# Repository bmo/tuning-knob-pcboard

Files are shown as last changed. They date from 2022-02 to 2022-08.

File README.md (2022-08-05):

# tuning-knob-pcboard  
https://github.com/bmo/tuning-knob-pcboard

This is a KiCAD PC Board design for a tuning knob that works with PowerSDR and SmartSDR and Remote Ham Radio (RHR). Uses STM32 hardware. Find the software that works with this here: https://github.com/bmo/hwcontrol

## Features:
- 24ppr encoder
- multiple ways to build it
- uses mostly-available STM32F103 "Blue Pill" PC boards, may also work with newer, more powerful, more available, and cheaper (!?) "Black Pill" PCBs using STM32F4xx CPUs (with code changes)
- through-hole parts
- 20-30 minute assembly
- traces already supplied for future expansion for footswitch inputs, flash memory, SPI-based displays
- works with RHR, PowerSDR, SmartSDR when used in conjunction with https://github.com/bmo/hwcontrol

## Version 1:
Build it two ways:
- snap-action tactile switches and 3mm LEDs
- small tactile switches with built-in LEDs
- isolated pin 40 to not prohibit "Black Pill" from being plugged in
hwcontrol_513k

## Version 2 (in Progress):
- Cherry MX or compatible "buttons"
- RGB LEDs for illumination

## Future:
- With a composite USB Device providing two CDC (serial) devices, a solution that provides a Knob and a de-bounced footswitch

## References:
- KiCAD library / design for Cherry Switch + RGB : https://github.com/sszczep/Cherry-MX-Breakout-Board

## Contributions
Thanks to @cjtheham for BOM and documentation!

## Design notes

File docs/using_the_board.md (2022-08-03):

All connections to a computer will be made by connecting a micro-USB cable to the STM-32 board, the other end into your computer/device.

# RemoteHamRadio

In order to use the board with RemoteHamRadio, you'll need to set it up like it is a FlexControl. 

Go to the devices tab on the bottom left-hand side. Go to the tab labeled FlexControl, click discover COM port, and then quickly unplug and re-plug in the USB cable for the device. RHR should detect the correct port and you'll be good to go to start using the VFO knob and tuning the bands.

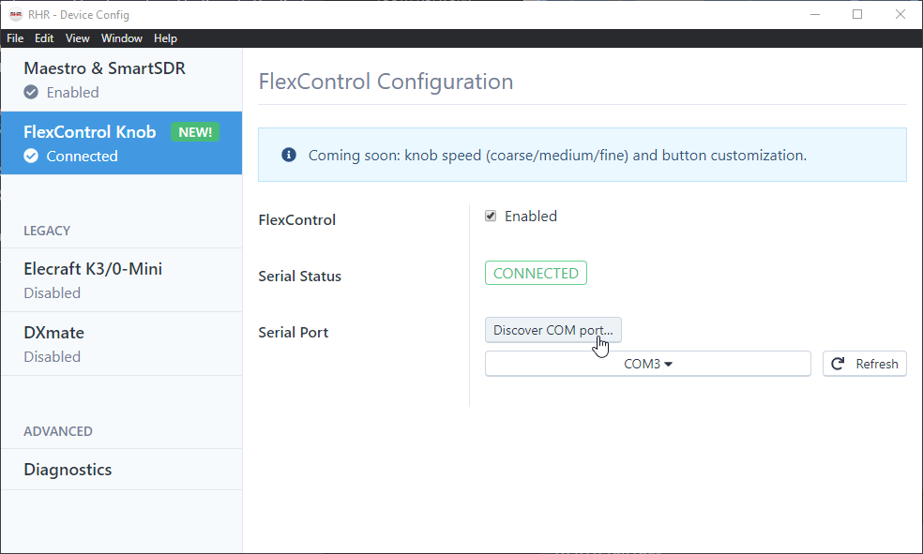
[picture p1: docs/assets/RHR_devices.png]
RemoteHamRadio devices panel for FlexControl


# SmartSDR

SmartSDR from Flex Radio should automatically detect the device, but sometimes it doesn't grab it right away. I've found that simply unplugging it, plugging it back in, and waiting around 20 seconds gets it to be recognized. From here, you'll automatically be able to start using it as a VFO knob.

If you want to change the features of the buttons, or clicking down on the knob, simply go to the tab at the top of the screen labeled Settings, and then click FlexControl. If the board is successfully connected, you'll be able to change the settings here.

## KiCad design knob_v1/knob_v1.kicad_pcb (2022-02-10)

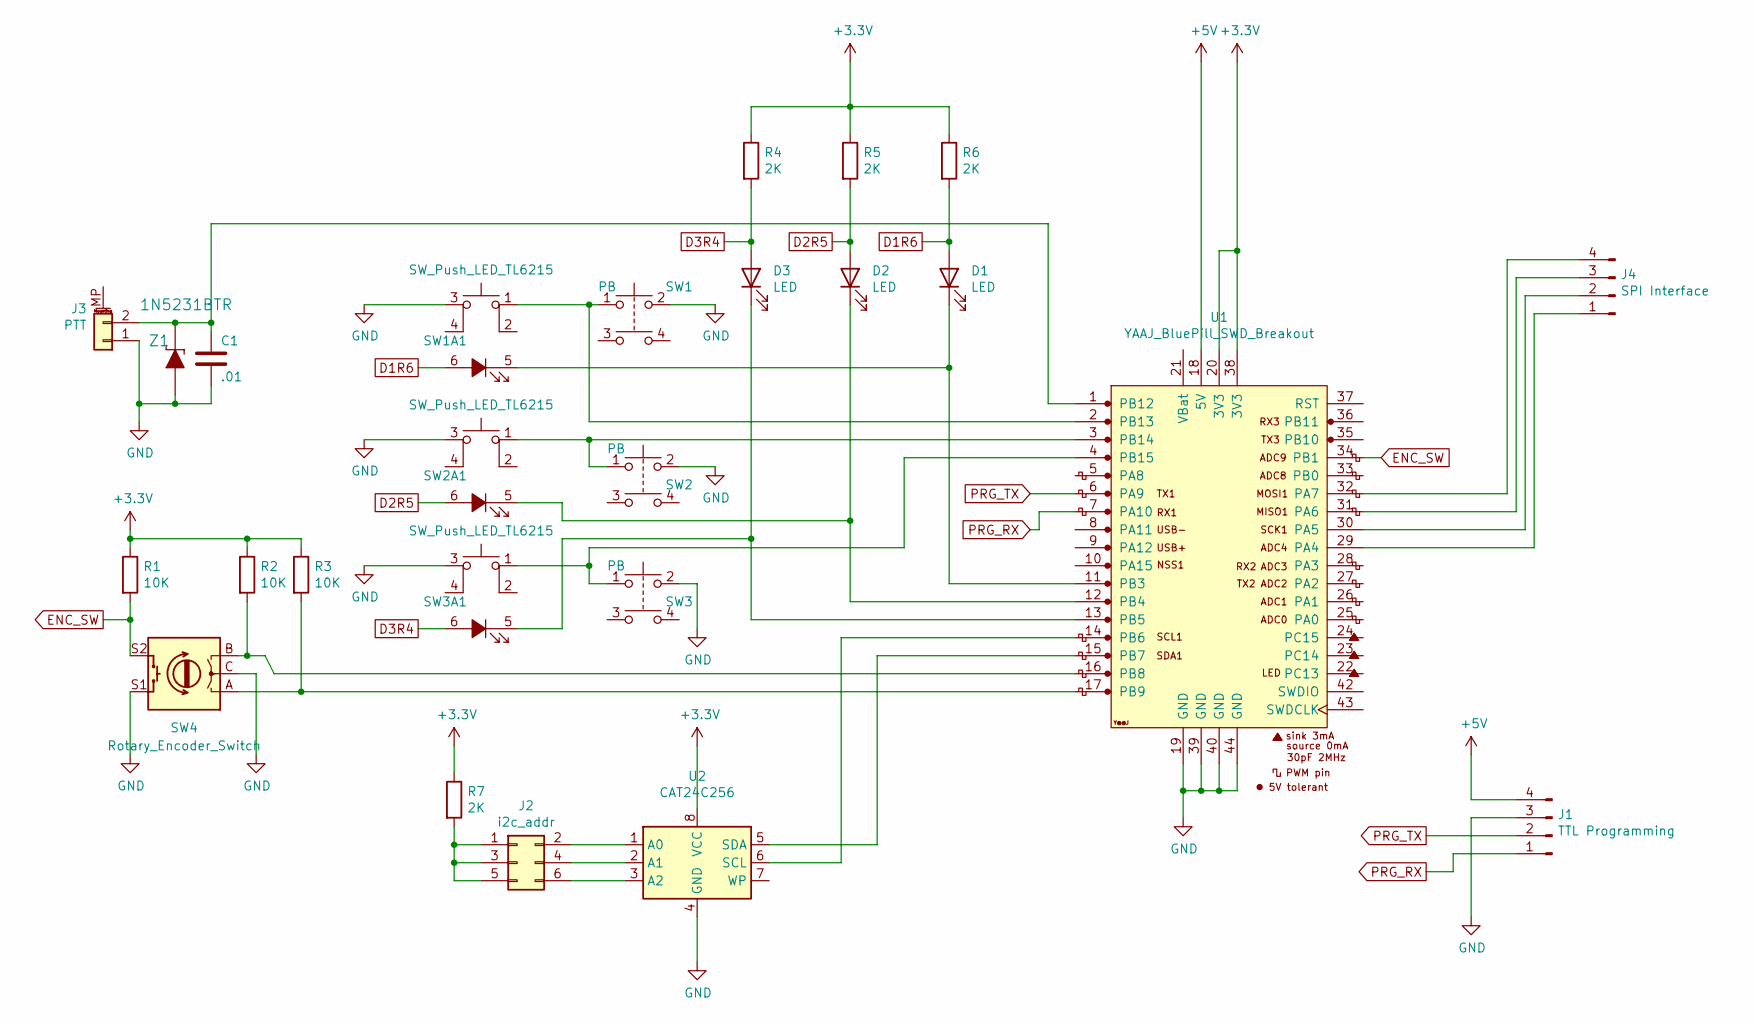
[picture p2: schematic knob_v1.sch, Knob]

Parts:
C1: .01; C_Disc_D3.0mm_W1.6mm_P2.50mm
D1, D2, D3: LED; LED_D3.0mm
J1: TTL Programming; PinHeader_1x04_P2.54mm_Vertical
J2: i2c_addr; PinHeader_2x04_P2.54mm_Vertical
J3: PTT; PinHeader_1x02_P2.54mm_Horizontal
J4: SPI Interface; PinHeader_1x04_P2.54mm_Vertical
R1, R2, R3: 10K; R_Axial_DIN0207_L6.3mm_D2.5mm_P7.62mm_Horizontal
R4, R5, R6, R7: 2K; R_Axial_DIN0207_L6.3mm_D2.5mm_P7.62mm_Horizontal
SW1, SW2, SW3: PB; SW_PUSH-12mm-corrected
SW1A1, SW2A1, SW3A1: SW_Push_LED_TL6215; TL6215V
SW4: Rotary_Encoder_Switch; RotaryEncoder_Alps_EC12E-Switch_Vertical_H20mm
U1: YAAJ_BluePill_SWD_Breakout; YAAJ_BluePill_SWD_1
U2: CAT24C256; SOIC8-1.27-5X4MM
Z1: 1N5231BTR; DO-35; MPN 1N5231BTR; Digi-Key_PN 1N5231BFSCT-ND

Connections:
+3V3: R1.1, R2.1, R3.1, R4.1, R5.1, R6.1, R7.1, U1.20 (3V3), U1.38 (3V3), U2.8 (VCC)
+5V: J1.4, U1.18 (5V)
D1R6: D1.2 (A), R6.2, SW1A1.6 (A)
D2R5: D2.2 (A), R5.2, SW2A1.6 (A)
D3R4: D3.2 (A), R4.2, SW3A1.6 (A)
ENC_SW: R1.2, SW4.S2, U1.34 (PB1)
GND: C1.2, J1.3, J3.1, SW1.2, SW1A1.3, SW2.2, SW2A1.3, SW3.2, SW3A1.3, SW4.C, SW4.S1, U1.19 (GND), U1.39 (GND), U1.40 (GND), U1.44 (GND), U2.4 (GND), Z1.A
unnamed: C1.1, J3.2, U1.1 (PB12), Z1.K
unnamed: D1.1 (K), SW1A1.5 (K), U1.11 (PB3)
unnamed: D2.1 (K), SW2A1.5 (K), U1.12 (PB4)
unnamed: D3.1 (K), SW3A1.5 (K), U1.13 (PB5)
unnamed: J2.1, J2.3, J2.5, R7.2
unnamed: J2.2, U2.1 (A0)
unnamed: J2.4, U2.2 (A1)
unnamed: J2.6, U2.3 (A2)
unnamed: J4.1, U1.29 (PA4)
unnamed: J4.2, U1.30 (PA5)
unnamed: J4.3, U1.31 (PA6)
unnamed: J4.4, U1.32 (PA7)
unnamed: R2.2, SW4.B, U1.16 (PB8)
unnamed: R3.2, SW4.A, U1.17 (PB9)
unnamed: SW1.1, SW1A1.1, U1.2 (PB13)
unnamed: SW2.1, SW2A1.1, U1.3 (PB14)
unnamed: SW3.1, SW3A1.1, U1.4 (PB15)
unnamed: U1.14 (PB6), U2.6 (SCL)
unnamed: U1.15 (PB7), U2.5 (SDA)
PRG_RX: J1.1, U1.7 (PA10)
PRG_TX: J1.2, U1.6 (PA9)

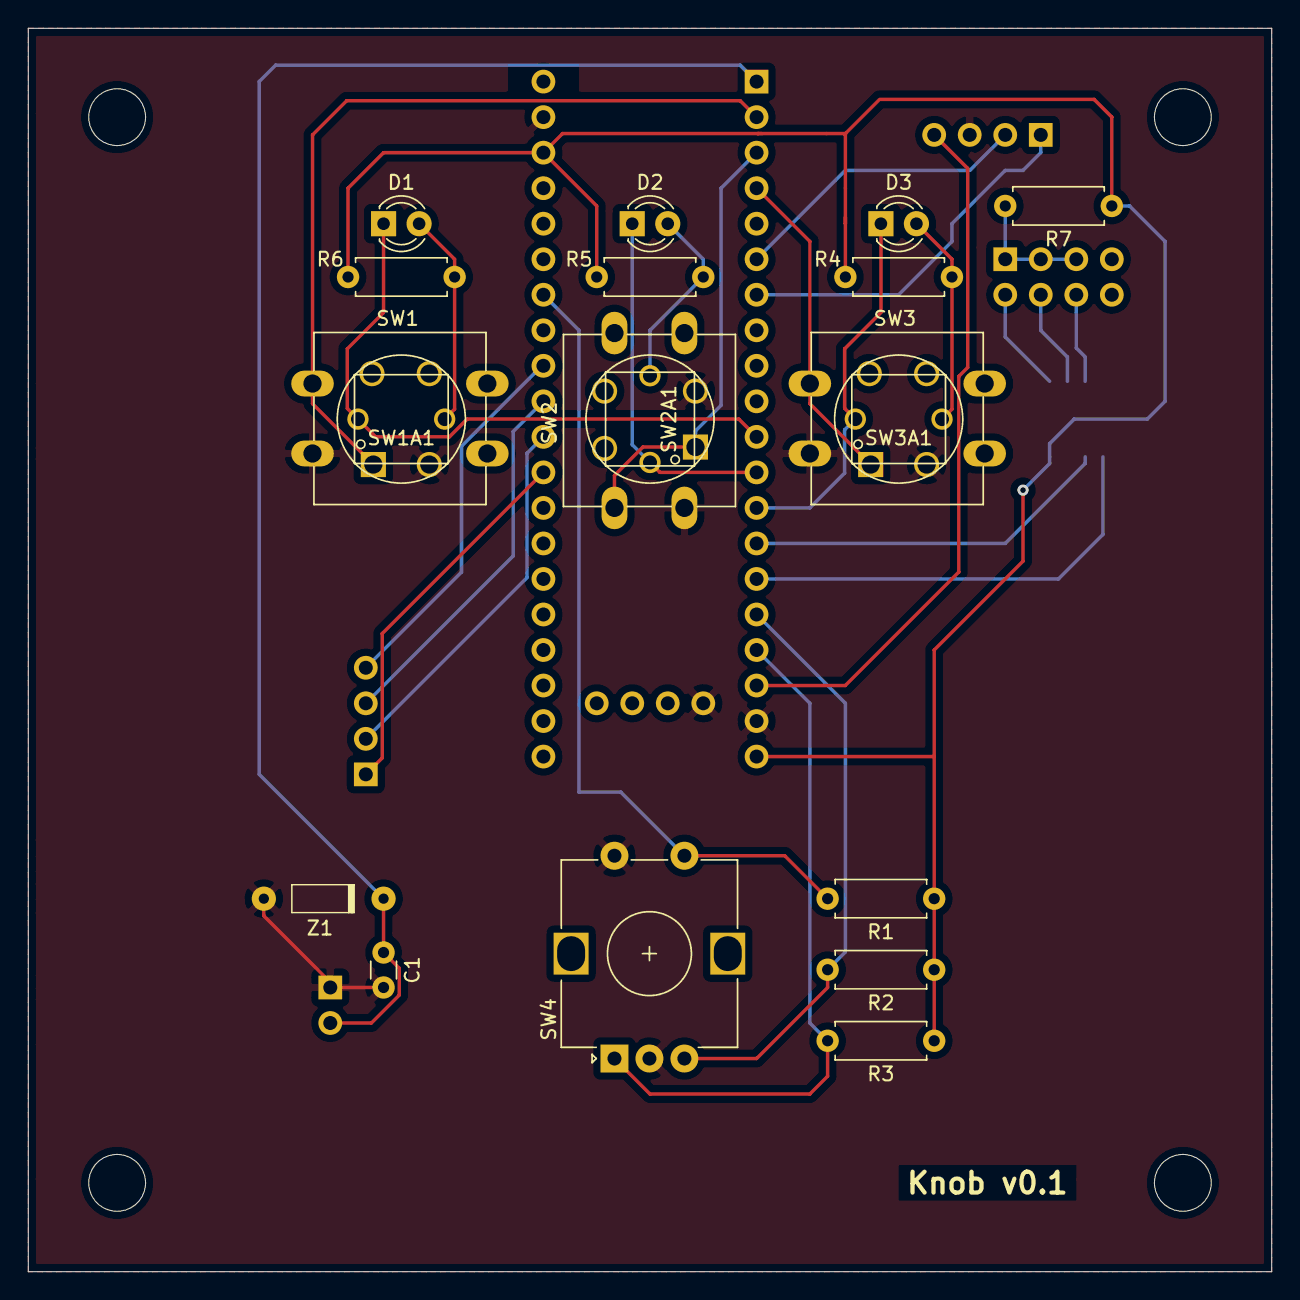
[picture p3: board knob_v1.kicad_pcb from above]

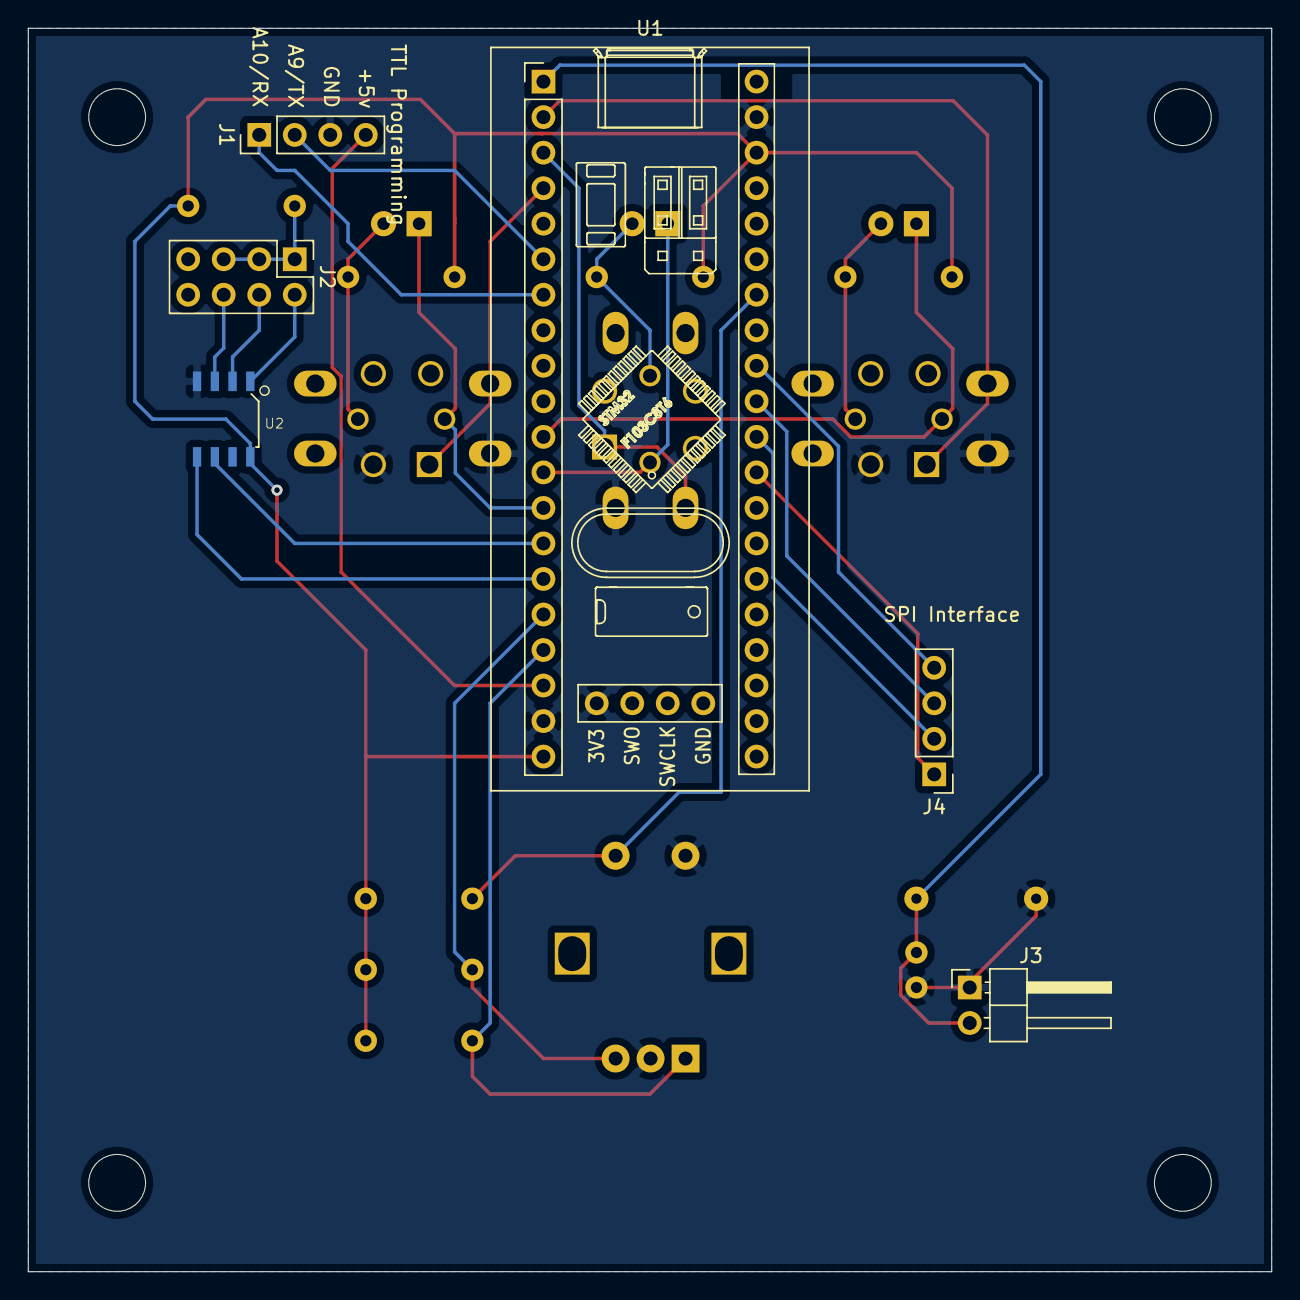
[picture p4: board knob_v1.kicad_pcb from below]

Board: 2 copper layers, 88.9 x 88.9 mm, 25 parts (6 on the bottom side), 28 nets.

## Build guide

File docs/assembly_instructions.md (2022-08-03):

> Note: if you are building your tuning knob using this documentation, we'd love if you are able to submit pictures as you progress through each step! Please feel free to make a PR with additional photos and resources.

# Bill of Materials (BoM)

Sources listed below were confirmed to work at the time of their addition. Please make a PR if you find new sources for parts that work or if any of these links become outdated.

* Tuning Knob PCB
* STM-32 "Blue Pill Board" - STM32F103C8T6
  * Recommended to purchase one with USB programming dongle (ST-Link V2)3
  * [Amazon - initeq](https://www.amazon.com/initeq-STM32F103C8T6-Minimum-Development-Programmer/dp/B079B95L9Y?th=1)
* 20 pin header Sockets
  * [Digikey](https://www.digikey.com/en/products/detail/sullins-connector-solutions/PPTC201LFBN-RC/810158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) - S7018-ND 
* 12x12x7.3mm Tactile Buttons
  * [Amazon - WOWOONE](https://a.co/d/htCCb7B)
* 3mm LEDs
* Digital Encoder
  * [Digikey](https://www.digikey.com/en/products/detail/bourns-inc/PEC11R-4015F-S0024/4499668)
* Knob (40, 42, 44mm) - PEC11R-4015F-S0024
  * [AliExpress](https://www.aliexpress.com/item/2251832815162496.html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)
* 3x 10k resistors
  * Found in any Resistor variety pack on Amazon or another retailer
* 3x 2k resistors
  * Found in any Resistor variety pack on Amazon or another retailer

# Building the Tuning Knob

## Pro Tips

* Be sure to check the value of the resistors if you have a multimeter handy! Resistors can usually be within +-5% of their expected value and still work fine.
* Resistors have no polarity, but LEDs do. Make sure you have them oriented the correct way before soldering.

## Step-by-step Instructions

1. At the very top of the board you'll find 3 rows of 3 through hole slots. Look for the slots labeled R6, R5, and R4. Place and solder 2k ohm resistors in each of these slots on the front side of the board (indicated by "Knob v0.1" in the bottom right hand side).
2. Place and solder 3mm LEDs above the resistors you just added in the D1, D2, and D3 slots. Make sure the long end goes in the circular pad, and the shorter end in the square pad.
3. Take your tactile buttons and solder them in SW1-3 slots. These should only fit in one of the slots, don't worry about the extra pads in that area yet. Do not place the plastic caps over the buttons before soldering.
4. Turn the board around to the side that does not have the knob version in the bottom right corner. Solder in your 20 pin header sockets for the STM-32 board. My preferred method of doing this is soldering on the 2 ends of each pad, and then doing a test fit to make sure it lines up right with the pins on the board before soldering the rest.
5. In the bottom right of the front side of the board, you'll see resistor slots R1, R2, and R3. Place and solder 10k ohm resistors in this slot.
6. Place and solder your digital encoder knob in the SW4 slot to the left of the newly placed resistors. This can only go in one way, so you should not have any issues with polarity. If you have trouble getting the sides in, I found it helpful to align the part, and then gently push in on the sides with the flat side of a pair of pliers till it slotted in.
7. Take your knob, and slide it over top of the digital encoder. You may find that it is very loose - this is normal! You'll need to take an allen wrench (3mm for me, but your mileage may vary), slide the knob up slightly, and tighten it down till you start feeling resistance.

You've now completed the hardware side of the build!

# Uploading Code

Find the code at the separate [bmo/hwcontrol](https://github.com/bmo/hwcontrol) repository!

To finish this build, you'll need to upload the software to the STM-32 board. Start by connecting your board to the ST-Link V2 dongle. 

From the ST-Link to the STM-32, the connections should be as follows:
* GND -> GND
* 3.3V -> 3.3
* SWDIO -> DIO
* SWCLK -> DCLI

## Compiling the Software 

If the most recent release is not up to date, you'll need to compile the software manually.

Then, download the [STM32Cube IDE](https://www.st.com/en/development-tools/stm32cubeide.html). Once you have this installed, you'll need to import the folder usbser1 from this repository into the IDE, and run a build using the hammer button at the top left corner (arrow next to it, 2: Release).

This will generate a file named usbser1.elf, that will be the uploaded code to the board.

## Flashing the Board

For this step, you'll need the [STM32CubeProg](https://www.st.com/en/development-tools/stm32cubeprog.html) software. 

With the STM-32 board connected to the USB dongle, open the programming software and press the green connect button in the top right. 

Then, click the "Download" button on the left hand side (arrow pointing down to a drive). You'll see a browse button where you can pick the usbser1.elf file, and then a start programming button. Once you upload the firmware you're done!

To confirm the upload worked correctly, go back to the first tab on the left hand side. Click the arrow next to read, and pick "Compare Memory with File", and then select the usbser1.elf file. This will read your boards flash memory and show you if everything is the exact same as the firmware file.

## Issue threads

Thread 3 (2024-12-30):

hi thanks

bh1nsn, 2024-12-30:
I am learning from your sharing, and I am very grateful. I have the following two questions. 1. Is the connection to the computer made directly through the Type-C interface of the STM32F103C8T6? 2. Can the RHR device configuration be shared? Thank you.

bmo, 2024-12-31:
The knob implements a serial communications port (USB CDC Device). The port connects via whatever physical hardware is present on the STM32 board (all of my "blue pill" boards have had micro-USB ports).

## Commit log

2022-02-10 commit plots
    [knob_v1-B_Cu.gbr, knob_v1-B_Mask.gbr, knob_v1-B_Paste.gbr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]
2022-08-03 assembly note + image
